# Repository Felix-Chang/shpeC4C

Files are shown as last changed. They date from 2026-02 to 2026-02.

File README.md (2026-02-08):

# BinSight

A smart waste management system that uses ultrasonic sensors on Raspberry Pi to monitor trash bin fill levels in real time. Bin data is sent to a cloud-hosted backend and displayed on a web dashboard with Google Maps integration and route optimization for collection crews.

## Overview

BinSight consists of three components:

- **Sensor** -- A Raspberry Pi with an HC-SR04 ultrasonic sensor mounted inside a trash bin. It measures the distance to the waste surface, calculates fill percentage, and sends telemetry to the backend over HTTP.
- **Backend** -- A FastAPI server that receives sensor telemetry, stores bin state in memory, and exposes a REST API for the frontend.
- **Frontend** -- A React + TypeScript dashboard that displays bin locations on a Google Map, color-coded by fill level. Includes a route planner that generates optimized pickup routes prioritizing the fullest bins.

## Goals

- Reduce unnecessary pickups by only dispatching collection when bins are full.
- Provide real-time visibility into bin fill levels across a campus or area.
- Optimize collection routes to minimize time and fuel usage.
- Demonstrate a low-cost IoT pipeline from sensor to cloud to dashboard.

## Project Structure

```
shpeC4C/
├── sensor/           Raspberry Pi sensor script
│   ├── main.py
│   ├── admin.py      Admin CLI for managing bins
│   ├── .env          Configuration file (create this!)
│   └── requirements.txt
├── backend/          FastAPI server
│   ├── main.py
│   ├── .env          Configuration file (create this!)
│   └── requirements.txt
├── frontend/         React + TypeScript dashboard
│   ├── src/
│   ├── .env          Configuration file (create this!)
│   └── package.json
└── README.md
```

## Running the Backend

Requires Python 3.10+.

```bash
cd backend
python -m venv .venv
source .venv/bin/activate
pip install -r requirements.txt
python main.py
```

The server starts on `http://localhost:8000`. Available endpoints:

| Method | Path | Description |
| --- | --- | --- |
| POST | `/telemetry` | Receive a sensor reading |
| GET | `/bins` | List all bins with latest data |
| GET | `/bins/{bin_id}` | Get a single bin |

For deployment, the backend is configured to run on Railway. A `Procfile` is needed:

```
web: uvicorn main:app --host 0.0.0.0 --port $PORT
```

## Running the Frontend

Requires Node.js 18+.

```bash
cd frontend
npm install
cp .env.example .env
```

Edit `.env` and fill in your values:

```
VITE_GOOGLE_MAPS_KEY=your_google_maps_api_key
VITE_API_URL=http://localhost:8000
```

The Google Maps API key must have the **Maps JavaScript API** enabled. Then start the dev server:

```bash
npm run dev
```

The dashboard will be available at `http://localhost:5173`.

## Raspberry Pi Sensor Setup

### Hardware

- Raspberry Pi (any model with GPIO)
- HC-SR04 ultrasonic distance sensor
- Voltage divider or level shifter for the Echo pin (3.3V logic)

### Wiring

| HC-SR04 Pin | RPi GPIO |
| --- | --- |
| Trig | GPIO 25  |
| Echo | GPIO 24  |
| VCC | 5V |
| GND | GND |

The Echo pin outputs 5V. Use a voltage divider (1k / 2k resistors) to bring it down to 3.3V for the Pi's GPIO input.

### Software

```bash
cd sensor
pip install -r requirements.txt
```

### Configuration

**Create a `.env` file** in the `sensor/` folder:

```bash
# sensor/.env
BACKEND_URL=http://localhost:8000
BIN_ID=bin-01
```

**Configuration Options:**

| Variable | Default | Description |
| --- | --- | --- |
| `BACKEND_URL` | `https://yourApp-production.up.railway.app` | Backend API base URL |
| `BIN_ID` | `bin-01` | Identifier for this bin |

> **Note:** For `main.py`, the URL should NOT include `/telemetry` - the script appends it automatically. For local testing, use `BACKEND_URL=http://localhost:8000`.

**Start the sensor:**

```bash
python main.py
```

The sensor takes 7 readings per cycle using a median filter, then sends the smoothed distance and calculated fill percentage to the backend every second.

### Admin Tool

The sensor folder includes an admin CLI tool for managing bins remotely:

```bash
cd sensor
python admin.py
```

Features:

- **List bins** - View all bins with fill levels and status
- **Add bin** - Register new bins with metadata (name, location)
- **Delete bin** - Remove bins from the system

The admin tool uses the same `.env` configuration as the sensor script.

### Calibration

In `sensor/main.py`, adjust these values to match your bin dimensions:

- `EMPTY_DISTANCE_CM` -- Distance from sensor to bottom of an empty bin (default: 60 cm)
- `FULL_DISTANCE_CM` -- Distance when the bin is considered full (default: 10 cm)

## License

This project was built for the SHPE Code4Change hackathon.

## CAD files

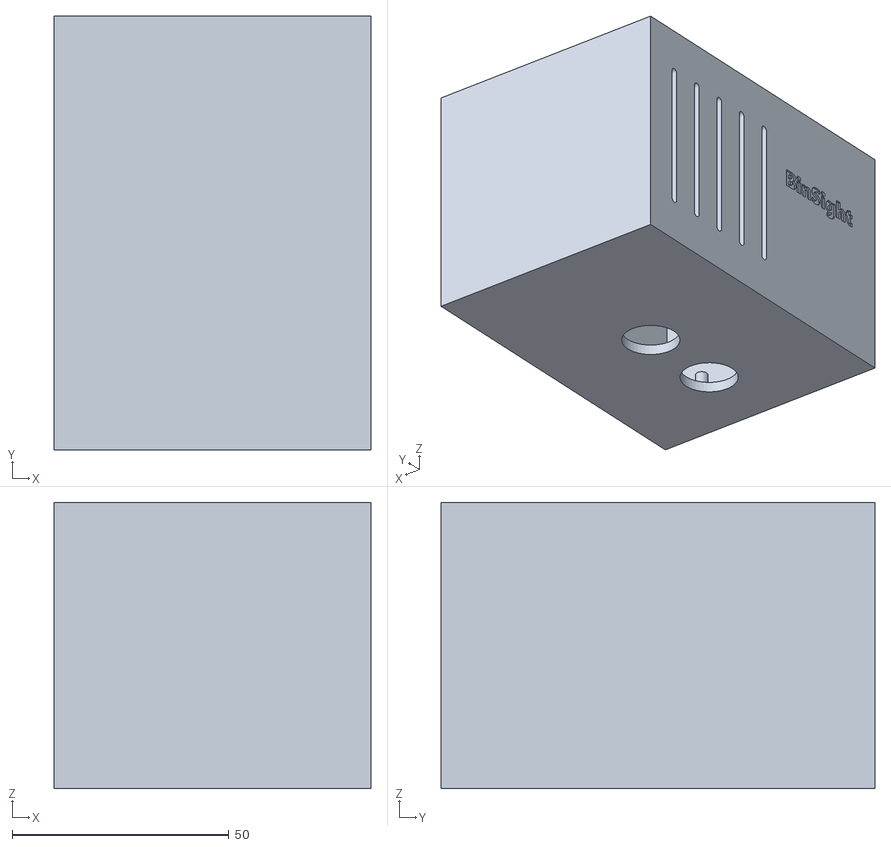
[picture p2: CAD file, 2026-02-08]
models/BinSight Case_Assembly.stl
73.0 x 100.0 x 66.0

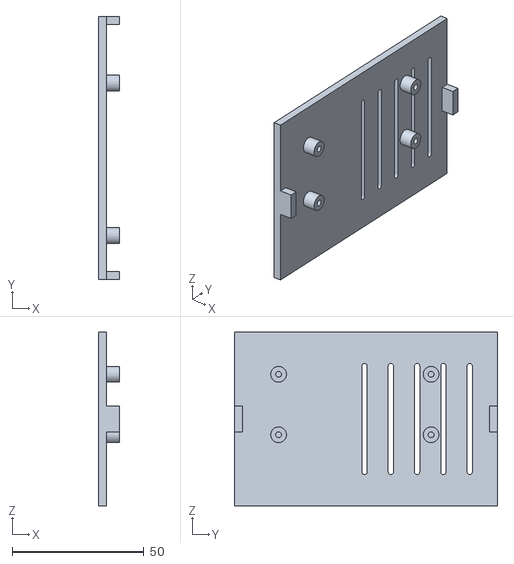
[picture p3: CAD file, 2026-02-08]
models/BinSight Case_Lid.stl
8.00 x 100.0 x 66.0

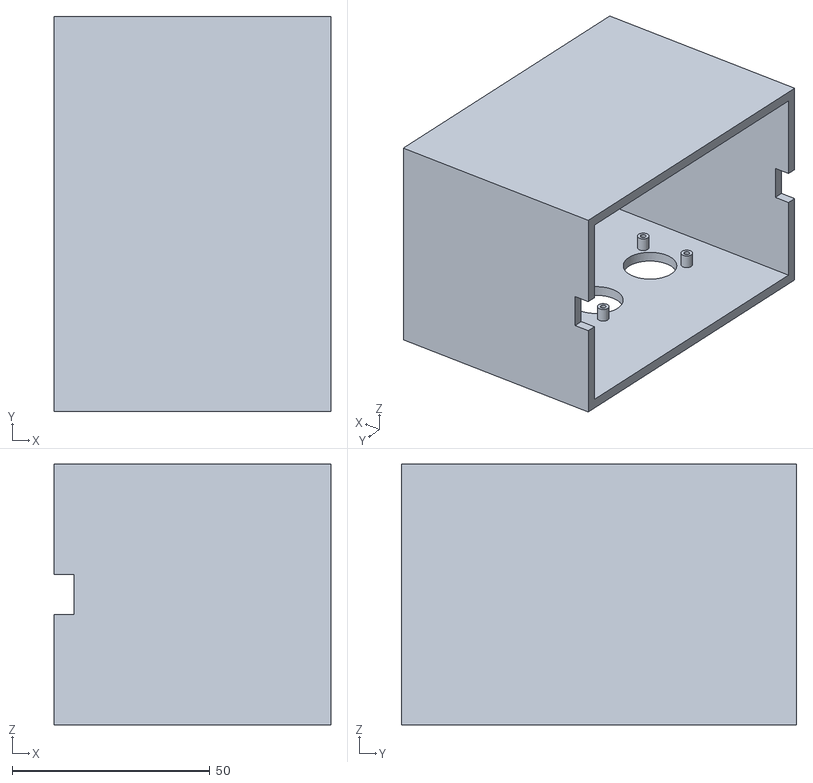
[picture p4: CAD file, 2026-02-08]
models/BinSight Base.stl
70.0 x 100.0 x 66.0

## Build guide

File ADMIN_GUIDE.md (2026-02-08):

# Admin Tool Guide

## Overview

The admin tool allows you to manage waste bins in the system - add new bins with complete metadata and delete bins when needed.

## Files

- **`sensor/admin.py`** - Interactive CLI admin tool
- **`backend/main.py`** - Contains the admin API endpoints

## API Endpoints

### POST /bins/register
Register or update bin metadata (name and location coordinates).

**Request:**
```json
{
  "bin_id": "bin-07",
  "name": "Norman Hall",
  "lat": 29.6475,
  "lng": -82.3420
}
```

**Response:**
```json
{
  "status": "created",  // or "updated" if bin already exists
  "bin_id": "bin-07"
}
```

**Behavior:**
- If bin doesn't exist: Creates new bin with metadata + initializes with 0% fill
- If bin exists: Updates name and location, preserves existing telemetry data
- Sets `last_emptied_at` to current time for new bins
- Initializes `distance_cm` to 60.0 (empty) and `fill_percent` to 0.0

### DELETE /bins/{bin_id}
Delete a bin from the system.

**Response:**
```json
{
  "status": "deleted",
  "bin_id": "bin-07"
}
```

**Behavior:**
- Returns 404 if bin doesn't exist
- Deletes bin document from `bins` collection
- Preserves telemetry history in `telemetry` collection for audit trail

## Using the Admin CLI

### 1. Configure Backend URL

The admin tool connects to your backend. Set the URL via environment variable:

```bash
# For local development
export BACKEND_URL=http://localhost:8000

# For production Railway deployment
export BACKEND_URL=https://your-app.up.railway.app
```

Or edit `BACKEND_URL` directly in `sensor/admin.py` (line 13).

### 2. Run the Admin Tool

```bash
cd sensor
python admin.py
```

### 3. Menu Options

```
1. List all bins       - Shows table of all registered bins with fill levels
2. Add new bin         - Register new bin with metadata + initial telemetry
3. Delete bin          - Remove bin from system (requires confirmation)
4. Exit               - Quit the tool
```

## Example Workflows

### Adding a New Bin

1. Select option **2** (Add new bin)
2. Enter bin details:
   ```
   Bin ID: bin-07
   Location Name: Norman Hall
   Latitude: 29.6475
   Longitude: -82.3420
   ```
3. Tool will:
   - Register metadata via `POST /bins/register`
   - Send initial telemetry (0% fill, 60cm distance)
   - Display success message

### Deleting a Bin

1. Select option **3** (Delete bin)
2. Enter bin ID to delete: `bin-07`
3. Confirm deletion: `y`
4. Tool will delete the bin via `DELETE /bins/{bin_id}`

### Listing Bins

1. Select option **1** (List all bins)
2. View table showing:
   - Bin ID
   - Location name
   - Current fill percentage
   - Status indicator (🟢 OK / 🟡 MEDIUM / 🔴 FULL)

## Backend Implementation Details

### Data Flow for New Bins

Before this feature:
```
Sensor → POST /telemetry → Bin auto-created with upsert=True
Problem: Missing name, location, last_emptied_at
```

After this feature:
```
Admin → POST /bins/register → Create bin with full metadata
                            → Initialize with 0% fill
Sensor → POST /telemetry → Update fill level
```

### MongoDB Schema

```json
{
  "bin_id": "bin-07",
  "name": "Norman Hall",
  "location": {"lat": 29.6475, "lng": -82.3420},
  "fill_percent": 0.0,
  "distance_cm": 60.0,
  "last_seen_at": 1770563300.28,
  "last_emptied_at": 1770563300.28
}
```

### Code Locations

**backend/main.py:**
- Line 36-40: `BinRegister` Pydantic model
- Line 225-258: `POST /bins/register` endpoint
- Line 260-271: `DELETE /bins/{bin_id}` endpoint

## Production Deployment

### Railway Backend

The admin tool works with your Railway-hosted backend. Just set:

```bash
export BACKEND_URL=https://your-railway-app.up.railway.app
```

### Security Considerations

⚠️ **Important:** These are admin-level endpoints without authentication.

For production, consider adding:
- API key authentication via headers
- Admin user authentication
- Rate limiting
- Audit logging of admin actions

Example quick fix (add to backend):
```python
API_KEY = os.getenv("ADMIN_API_KEY", "your-secret-key")

@app.post("/bins/register")
def register_bin(data: BinRegister, api_key: str = Header(None)):
    if api_key != API_KEY:
        raise HTTPException(status_code=401, detail="Unauthorized")
    # ... rest of endpoint
```

## Testing

Run automated tests:

```bash
# Start backend
cd backend
source .venv/bin/activate
python main.py

# In another terminal, run tests
cd /Users/felixchang/Desktop/shpeC4C
python test_admin_endpoints.py
```

## Troubleshooting

### "Could not connect to backend"
- Verify backend is running: `curl http://localhost:8000/bins`
- Check BACKEND_URL is correct
- For Railway: verify app is deployed and URL is correct

### "Bin already exists"
- This is expected behavior - use option 1 to list bins first
- Delete the old bin if you want to recreate it

### Changes not appearing in frontend
- Frontend must fetch data from `/bins` endpoint
- Refresh the dashboard to see new bins
- Check browser console for API errors

## Future Enhancements

- [ ] Batch import from CSV: `admin.py import bins.csv`
- [ ] Update endpoint: `PATCH /bins/{bin_id}` for editing metadata
- [ ] Soft delete with `deleted: true` flag instead of hard delete
- [ ] Web-based admin dashboard (no CLI needed)
- [ ] Audit log: track who added/deleted bins and when

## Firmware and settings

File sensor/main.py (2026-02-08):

import os
import time
import statistics
import RPi.GPIO as GPIO
import requests
from dotenv import load_dotenv

# Load environment variables from .env file
load_dotenv()

# ----------------------------
# CONFIG
# ----------------------------
TRIG_PIN = 25   # BCM GPIO23 (physical pin 16)
ECHO_PIN = 24   # BCM GPIO24 (physical pin 18) <-- use a voltage divider/level shifter if echo is 5V

# Trash bin calibration (in centimeters)
EMPTY_DISTANCE_CM = 60.0
FULL_DISTANCE_CM = 10.0

# Sampling
SAMPLES = 7
SAMPLE_DELAY = 0.08  # seconds between samples

# Env-var driven config
SEND_HTTP = True
BACKEND_URL = os.environ.get("BACKEND_URL", "https://shpec4c-production.up.railway.app/telemetry")
BIN_ID = os.environ.get("BIN_ID", "bin-01")
POST_INTERVAL = float(os.environ.get("POST_INTERVAL", "30"))  # seconds between backend posts
READ_INTERVAL = 5.0  # seconds between sensor readings (keeps sensor responsive)

# HC-SR04-ish constants
SPEED_OF_SOUND_CM_S = 34300.0  # cm/s at ~20°C
TIMEOUT_S = 0.03               # ~30ms covers up to ~5m round trip; you can lower since bins are close

# ----------------------------
# GPIO SETUP
# ----------------------------
GPIO.setmode(GPIO.BCM)
GPIO.setup(TRIG_PIN, GPIO.OUT)
GPIO.setup(ECHO_PIN, GPIO.IN)

GPIO.output(TRIG_PIN, GPIO.LOW)
time.sleep(0.1)  # settle sensor

def clamp(x, lo, hi):
    return max(lo, min(hi, x))

def distance_cm():
    """
    Trigger ultrasonic pulse and measure echo time.
    Returns distance in cm, or None on timeout.
    """
    # Send 10us trigger pulse
    GPIO.output(TRIG_PIN, GPIO.HIGH)
    time.sleep(0.00001)
    GPIO.output(TRIG_PIN, GPIO.LOW)

    # Wait for echo to go HIGH (start)
    start_wait = time.time()
    while GPIO.input(ECHO_PIN) == 0:
        if time.time() - start_wait > TIMEOUT_S:
            return None
    pulse_start = time.time()

    # Wait for echo to go LOW (end)
    end_wait = time.time()
    while GPIO.input(ECHO_PIN) == 1:
        if time.time() - end_wait > TIMEOUT_S:
            return None
    pulse_end = time.time()

    pulse_duration = pulse_end - pulse_start  # seconds

    # Distance: (time * speed_of_sound) / 2
    d_cm = (pulse_duration * SPEED_OF_SOUND_CM_S) / 2.0

    # Basic sanity filter (tweak if needed)
    if d_cm <= 0 or d_cm > 400:  # many sensors are reliable up to ~400cm
        return None

    return d_cm

def smoothed_distance_cm():
    readings = []
    for _ in range(SAMPLES):
        d = distance_cm()
        if d is not None:
            readings.append(d)
        time.sleep(SAMPLE_DELAY)

    if not readings:
        return None

    return statistics.median(readings)

def fill_percent_from_distance(d_cm):
    if d_cm is None:
        return None
    fill = (EMPTY_DISTANCE_CM - d_cm) / (EMPTY_DISTANCE_CM - FULL_DISTANCE_CM) * 100.0
    return clamp(fill, 0.0, 100.0)

def send_to_backend(d_cm, fill_pct):
    payload = {
        "bin_id": BIN_ID,
        "distance_cm": d_cm,
        "fill_percent": fill_pct,
        "ts": time.time(),
    }
    try:
        r = requests.post(BACKEND_URL, json=payload, timeout=3)
        r.raise_for_status()
        print(f"Sent: {payload}")
    except Exception as e:
        print(f"Send failed: {e}")

def main():
    print(f"Starting ultrasonic monitoring (RPi.GPIO)...")
    print(f"Reading every {READ_INTERVAL}s, posting every {POST_INTERVAL}s")
    last_post_time = 0  # Force initial post

    try:
        while True:
            d = smoothed_distance_cm()
            fill = fill_percent_from_distance(d)
            current_time = time.time()

            if d is None or fill is None:
                print("No valid reading")
            else:
                print(f"Distance: {d:6.1f} cm | Fill: {fill:5.1f}%")

                # Only post if enough time has elapsed since last post
                if SEND_HTTP and (current_time - last_post_time >= POST_INTERVAL):
                    send_to_backend(d, fill)
                    last_post_time = current_time

            time.sleep(READ_INTERVAL)
    finally:
        GPIO.cleanup()

if __name__ == "__main__":
    main()

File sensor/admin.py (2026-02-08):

#!/usr/bin/env python3
"""
Admin CLI for managing waste bins.
Supports adding new bins with metadata and deleting bins.
"""
import os
import requests
import sys
import time
from datetime import datetime
from dotenv import load_dotenv

# Load environment variables from .env file
load_dotenv()

# Backend URL - use Railway production or local
BACKEND_URL = os.getenv(
    "BACKEND_URL",
    "https://shpec4c-production.up.railway.app"  # Fallback if not in .env
)

def calculate_distance(fill_pct: float) -> float:
    """Calculate distance_cm from fill percentage (mirrors backend logic)."""
    empty_dist = 60.0
    full_dist = 10.0
    return round(empty_dist - (fill_pct / 100.0) * (empty_dist - full_dist), 1)

def send_to_backend(endpoint: str, method: str = "GET", data: dict = None) -> dict:
    """Send HTTP request to backend."""
    url = f"{BACKEND_URL}{endpoint}"
    try:
        if method == "GET":
            response = requests.get(url, timeout=10)
        elif method == "POST":
            response = requests.post(url, json=data, timeout=10)
        elif method == "DELETE":
            response = requests.delete(url, timeout=10)
        else:
            raise ValueError(f"Unsupported method: {method}")

        response.raise_for_status()
        return response.json()
    except requests.exceptions.RequestException as e:
        print(f"❌ Error communicating with backend: {e}")
        sys.exit(1)

def list_bins():
    """List all bins in the system."""
    print("\n📋 Fetching bin list...")
    bins = send_to_backend("/bins")

    if not bins:
        print("No bins registered in the system.")
        return

    print(f"\n{'Bin ID':<15} {'Name':<25} {'Fill %':<8} {'Status':<10}")
    print("=" * 70)

    for bin_data in bins:
        bin_id = bin_data["bin_id"]
        name = bin_data["name"]
        fill = bin_data["fill_percent"]

        # Determine status based on fill level
        if fill >= 80:
            status = "🔴 FULL"
        elif fill >= 50:
            status = "🟡 MEDIUM"
        else:
            status = "🟢 OK"

        print(f"{bin_id:<15} {name:<25} {fill:<8.1f} {status:<10}")

    print(f"\nTotal bins: {len(bins)}")

def add_bin():
    """Add a new bin with metadata."""
    print("\n➕ Add New Bin")
    print("=" * 50)

    # Get bin details from user
    bin_id = input("Bin ID (e.g., bin-07): ").strip()
    if not bin_id:
        print("❌ Bin ID cannot be empty")
        return

    name = input("Location Name (e.g., Norman Hall): ").strip()
    if not name:
        print("❌ Name cannot be empty")
        return

    try:
        lat = float(input("Latitude (e.g., 29.6475): ").strip())
        lng = float(input("Longitude (e.g., -82.3420): ").strip())

        # NEW: Optional fill percentage
        fill_input = input("Initial fill % (0-100, press Enter for 0): ").strip()
        if fill_input:
            fill_percent = float(fill_input)
            if not 0 <= fill_percent <= 100:
                print("❌ Fill percentage must be between 0 and 100")
                return
        else:
            fill_percent = 0.0

    except ValueError:
        print("❌ Invalid input")
        return

    # Register bin metadata
    print(f"\n📝 Registering metadata for {bin_id}...")
    data = {
        "bin_id": bin_id,
        "name": name,
        "lat": lat,
        "lng": lng,
        "fill_percent": fill_percent
    }
    result = send_to_backend("/bins/register", method="POST", data=data)

    if result["status"] == "created":
        print(f"✅ Bin {bin_id} created successfully!")
    else:
        print(f"✅ Bin {bin_id} metadata updated!")

    # Send initial telemetry
    print("\n📡 Initializing sensor data...")
    distance = calculate_distance(fill_percent)
    telemetry = {
        "bin_id": bin_id,
        "distance_cm": distance,
        "fill_percent": fill_percent,
        "ts": time.time()
    }
    send_to_backend("/telemetry", method="POST", data=telemetry)
    print(f"✅ Success: Telemetry sent ({fill_percent}% fill, {distance}cm distance)")

def delete_bin():
    """Delete a bin from the system."""
    print("\n🗑️  Delete Bin")
    print("=" * 50)

    bin_id = input("Bin ID to delete: ").strip()
    if not bin_id:
        print("❌ Bin ID cannot be empty")
        return

    # Confirm deletion
    confirm = input(f"⚠️  Confirm delete {bin_id}? (y/n): ").strip().lower()
    if confirm != 'y':
        print("❌ Deletion cancelled")
        return

    # Delete bin
    print(f"\n🗑️  Deleting {bin_id}...")
    result = send_to_backend(f"/bins/{bin_id}", method="DELETE")
    print(f"✅ {result['status'].capitalize()}: {bin_id}")

def show_menu():
    """Display the main menu."""
    print("\n" + "=" * 50)
    print("🗑️  Waste Management Admin Tool")
    print("=" * 50)
    print("1. List all bins")
    print("2. Add new bin")
    print("3. Delete bin")
    print("4. Exit")
    print("=" * 50)

def main():
    """Main menu loop."""
    print(f"Backend URL: {BACKEND_URL}")

    while True:
        show_menu()
        choice = input("\nSelect option (1-4): ").strip()

        if choice == "1":
            list_bins()
        elif choice == "2":
            add_bin()
        elif choice == "3":
            delete_bin()
        elif choice == "4":
            print("\n👋 Goodbye!")
            sys.exit(0)
        else:
            print("❌ Invalid option. Please select 1-4.")

        input("\nPress Enter to continue...")

if __name__ == "__main__":
    try:
        main()
    except KeyboardInterrupt:
        print("\n\n👋 Goodbye!")
        sys.exit(0)

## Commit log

2026-02-08 setting up mongoDB with railway
2026-02-08 sensor testing
2026-02-08 backend logic, polyline, sensor
2026-02-08 changed pin numbers
2026-02-08 Added .stl files
    [BinSight Base.stl, BinSight Case_Assembly.stl, BinSight Case_Lid.stl]
2026-02-08 fill fixes for admin
    [admin.py, main.py]
2026-02-08 readme and sensor env
2026-02-08 sensor env example
2026-02-08 sensor post frequency reduced
2026-02-08 landing page
